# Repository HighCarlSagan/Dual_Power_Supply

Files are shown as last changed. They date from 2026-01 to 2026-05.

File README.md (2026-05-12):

# Universal PSU — 4A Dual-Output Power Supply






A compact mains-input dual-output bench supply built around an isolated AC-DC brick and two integrated buck modules. Provides clean, regulated 5 V and 3.3 V rails for hobby electronics — bench bringup, MCU dev boards, sensors, LEDs, and small actuator loads.

<p align="center">
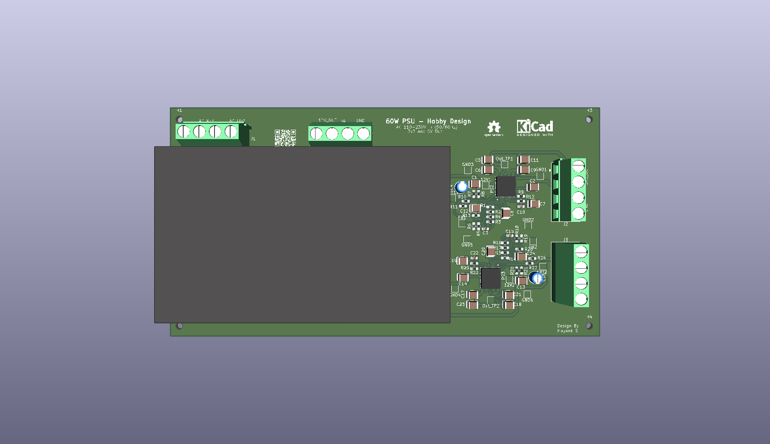
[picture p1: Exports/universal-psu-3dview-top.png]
PCB top render
  
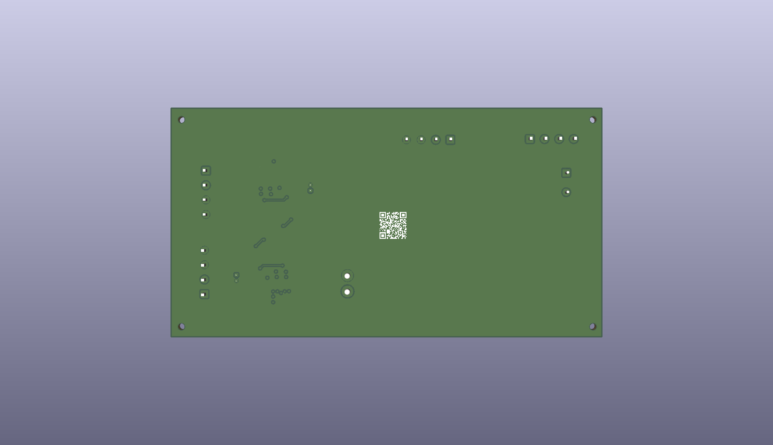
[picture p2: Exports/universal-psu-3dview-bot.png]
PCB bottom render
  
</p>

---

## Why I Built This

I wanted a single, always-on bench supply that I could leave plugged in and tap into for anything I'm prototyping: ESP32s, Pis, sensor breakouts, the Telegram-controlled lights board, whatever.

This was also a deliberate learning project on two fronts:

- **4-layer PCB layout for power applications** — getting the ground plane right, thermal management on the regulator footprints, and clean current return paths in a real-world design rather than a textbook example.
- **Mains-isolated module integration** — using a certified AC-DC brick lets me keep the dangerous side fully encapsulated while still building a useful, mains-powered project. A natural stepping stone before I take on a discrete flyback design later.

---

## Initial Requirements

These were the spec points I wrote down before any design work. The "Outcome" column shows what actually shipped.

| # | Requirement | Target | Outcome |
|---|---|---|---|
| 1 | Universal AC input | 110–230 V AC, 50/60 Hz | ✅ Met (IRM-60-15) |
| 2 | Output rail A | 5 V regulated | ✅ Met |
| 3 | Output rail B | 3.3 V regulated | ✅ Met |
| 4 | Continuous current per rail | 6 A | ⚠️ **4 A** — part ordered was TLVM14406 (4 A), not a 6 A variant. Sufficient for intended loads, scope kept. |
| 5 | Total power budget | ~60 W | ✅ Met (IRM-60-15 = 60 W headroom; DC-DC stage caps actual deliverable lower) |
| 6 | Form factor | Compact, no specific dimensions | ✅ 150 × 80 mm, 4-layer |
| 7 | Output protection (OCP, OVP) | TVS + fuse on outputs | ❌ **Missed in V1** — see [MkII Wishlist](#mkii-wishlist) |
| 8 | Status LEDs | Per-rail power-good indicators | ❌ **Missed in V1** — see [MkII Wishlist](#mkii-wishlist) |
| 9 | Reliability target | 3–4 years continuous service | TBD post-test |

---

## Specifications

| Parameter | Value |
|---|---|
| Input voltage | 110–230 V AC |
| Input frequency | 50 / 60 Hz |
| Intermediate rail | 15 V DC (internal only, see [Future Options](#future-options)) |
| Output 1 | 5 V @ 4 A |
| Output 2 | 3.3 V @ 4 A |
| Total output power | ~33 W deliverable from DC-DC stage<br>(60 W brick headroom) |
| PCB | 4-layer FR-4, 1.6 mm |
| Dimensions | 150 × 80 mm |
| Mounting | 4× M2 corner holes |
| Connectors | 4× 4-pin screw terminal blocks |

---

## Architecture

```
   AC Mains              Isolated brick           DC-DC stage              Outputs
  ┌─────────┐         ┌──────────────┐        ┌──────────────┐         ┌─────────┐
  │ 110-230 │────────▶│  IRM-60-15   │───15V─▶│ TLVM14406 #1 │────5V──▶│  J3     │
  │  V AC   │         │   60W AC-DC  │   │    └──────────────┘         └─────────┘
  └─────────┘         └──────────────┘   │    ┌──────────────┐         ┌─────────┐
                                         └───▶│ TLVM14406 #2 │────3.3V▶│  J4     │
                                              └──────────────┘         └─────────┘
```

The mains side is fully handled by the certified Mean Well IRM-60-15 brick. Everything on the PCB downstream is low-voltage DC, so the layout focused on thermal performance, ground-plane integrity, and switching-loop minimization rather than mains-side concerns.

---

## Key Components

| Reference | Part | Function |
|---|---|---|
| PS1 | Mean Well IRM-60-15 | 60 W universal-input AC-DC brick, 15 V output, fully isolated |
| PS2 | TI TLVM14406RCHR | Integrated 4 A SWIFT buck module, configured for 5 V |
| PS3 | TI TLVM14406RCHR | Integrated 4 A SWIFT buck module, configured for 3.3 V |
| J1–J4 | 4-pin screw terminals | Mains input, intermediate, and two output rails |

### Why the IRM-60 + TLVM14406 combo?

- **AC-DC brick over discrete flyback** — I wanted a reliable, working solution I could trust to leave running for years, without first having to learn off-line converter design, transformer winding, EMI compliance, and creepage/clearance. The IRM-60 is certified, isolated, and lets me focus the project on the DC-DC stage.
- **TLVM14406 over discrete switcher + inductor** — I'd worked with this family before. The integrated module collapses the inductor selection, compensation network design, and layout-critical switching loop into a known-good footprint. Fast path to a board that works.

---

## Connector Pinout

All four screw terminals share the same convention:

| Pin | Function |
|---|---|
| 1 | Power (V+) |
| 2 | Power (V+) |
| 3 | GND |
| 4 | GND |

Doubling power and ground pins lets each rail handle its rated current without exceeding terminal current limits and gives a cleaner mechanical termination for thicker wires.

| Connector | Use |
|---|---|
| J1 | AC mains input (Live / Neutral / Earth — see silkscreen) |
| J2 | 15 V intermediate (test point only — not for external loads in V1) |
| J3 | 5 V output |
| J4 | 3.3 V output |

---

## Repository Structure

```
universal-psu/
├── Exports/
│   ├── Gerber/                       # Production gerbers + drill files
│   ├── Photos/                       # Real PCB photos (added after assembly)
│   │   └── Testing/                  # Bench test photos & scope captures
│   ├── schematic.pdf                 # Full schematic export
│   ├── universal-psu-3dview-top.png  # PCB 3D render — top
│   ├── universal-psu-3dview-bot.png  # PCB 3D render — bottom
│   ├── universal-psu_bom.csv         # Bill of materials
│   ├── universal_psu_gerbers.zip     # Zipped gerbers for fab upload
│   └── universal-psu.net             # Netlist
├── Subsheets/
│   ├── DC_DC_Converter_5V.kicad_sch  # 5 V rail subsheet
│   └── DC_DC_Converter_3v3.kicad_sch # 3.3 V rail subsheet
├── libraries/                        # Custom KiCad symbols, footprints, 3D models
├── universal-psu.kicad_pro           # KiCad project
├── universal-psu.kicad_sch           # Top-level schematic
├── universal-psu.kicad_pcb           # PCB layout
├── LICENSE                           # CERN-OHL-P-2.0
└── README.md
```

---

## Bringup & Testing

> **Status:** PCBs back from fab, assembly in progress. Bringup test results will be posted in this section as they're collected.

### Planned bringup procedure

1. **Visual inspection** — solder bridges, especially around the AC-DC module and the screw terminal footprints
2. **Continuity check (power off)** — input-to-output isolation, no shorts on either rail
3. **Mains-up with no DC-side load** — verify 15 V intermediate rail comes up cleanly from the IRM-60 brick
4. **DC-DC bringup, no load** — verify 5 V and 3.3 V come up to spec (sanity-check the feedback divider math against measurement; resistor values to be verified during this step)
5. **Light load test** — 100 mA per rail, check ripple on a scope
6. **Stepped load test** — 0.5 A → 1 A → 2 A → 3 A → 4 A per rail, log:
   - DC output voltage (line/load regulation)
   - Output ripple (peak-to-peak)
   - Brick case temperature
   - TLVM14406 case temperature (thermal cam)
   - Input current draw (for a rough efficiency number)
7. **Thermal soak** — full load on both rails for 1 hour, log temperatures every 5 minutes

### Test results

*To be added in `Exports/Photos/Testing/` — scope captures, thermal images, and a bench-test summary table.*

| Test | Target | Measured | Notes |
|---|---|---|---|
| 5 V rail accuracy | 4.95 – 5.05 V | _TBD_ | |
| 3.3 V rail accuracy | 3.25 – 3.35 V | _TBD_ | |
| 5 V ripple @ 4 A | < 50 mV pp | _TBD_ | |
| 3.3 V ripple @ 4 A | < 50 mV pp | _TBD_ | |
| Brick temp @ full load | < 70 °C case | _TBD_ | |
| TLVM14406 temp @ 4 A | < 85 °C case | _TBD_ | |
| Line regulation | < 1 % | _TBD_ | |
| Load regulation | < 2 % | _TBD_ | |

---

## When To Use This Board

**Good fit:**
- Powering MCU dev boards (ESP32, RP2040, STM32 Nucleo, Pi Pico)
- Sensor breakouts, LCD modules, small displays
- LED strips and controllers (within 4 A budget)
- General benchtop hobby work where 5 V and 3.3 V are needed simultaneously

**Not a good fit:**
- Motor drives or anything inductive that kicks back significantly (no protection on V1)
- Audio circuits (no LC post-filtering for low-noise applications)
- Safety-critical or always-on industrial use (fuses and TVS missing on V1)
- Loads above 4 A continuous per rail

---

## Future Options

- **Expose 15 V intermediate as a third output** — already present internally, just needs a connector and trace fanned out. Useful for op-amp circuits, fan drives, or any project that wants a higher rail.
- **Output protection** — eFuse or polyfuse + TVS on each output rail.
- **Per-rail status LEDs** — power-good indicators tied to the TLVM14406 PG output.
- **3D-printed enclosure** — open-frame is fine for the bench, but a printed case would make this safer to leave plugged in long-term.

---

## MkII Wishlist

Honest list of what V1 missed that V2 should fix:

1. **Output protection** — no TVS, no fuses, no eFuses. A short on either output goes directly to the buck module's internal protection only.
2. **Status LEDs** — no visible indication that either rail is alive.
3. **Mounting hole placement** — corner holes are too close to the board edge, making the board awkward to mount in any standard enclosure. V2 should use rounded corners and proper standoff offsets.
4. **Silkscreen labeling** — connector pin functions need clearer markings on the board face.
5. **15 V tap connector** — needs a header.

---

## Manufacturing

Boards fabricated as standard 4-layer FR-4. Gerbers in `Exports/Gerber/` are compatible with JLCPCB, PCBWay, OSHPark, and similar fab houses.

**Fab specs used:**
- 4-layer, 1.6 mm FR-4
- 1 oz copper outer + inner
- ENIG surface finish recommended for finer pitch parts
- Default solder mask, white silkscreen

---

## Safety

> ⚠️ **DANGER — MAINS VOLTAGE**
>
> This board operates at 110–230 V AC. The mains-side energy can be lethal.
>
> The mains side is encapsulated inside the certified IRM-60-15 brick — no exposed mains-voltage traces exist on the PCB itself once the brick is mounted. However, the screw terminal carrying mains input (J1) and the brick's own input pins are exposed and must be enclosed before powering up.
>
> - Never operate without proper insulation around J1 and the brick's input side
> - Do not bypass or modify the AC-DC brick
> - Use a current-limited isolation transformer for first power-on if you have one available
> - Comply with local electrical codes
> - Not for medical, life-support, or safety-critical use
>
> **The author assumes no liability for injury, death, or property damage.**

---

## License

This project is licensed under the **CERN Open Hardware Licence Version 2 — Permissive (CERN-OHL-P-2.0)**.

You are free to:
- Use, modify, and distribute the design — commercially or non-commercially
- Create derivative works under any license you choose
- Use without sharing modifications back upstream

You must:
- Retain the original license notice and attribution

See [LICENSE](LICENSE) for the full text.

---

## Used By

This board powers the following projects in my portfolio:
- [PC_and_Light_Controller](https://github.com/HighCarlSagan/PC_and_Light_Controller) — Telegram-controlled UPS button + LED switching

---

## Author

**Mayank S (HighCarlSagan)** — [GitHub @HighCarlSagan](https://github.com/HighCarlSagan) · [highcarlsagan.dev](https://highcarlsagan.dev)

Designed: December 2025 · Boards back: April 2026 · Bringup: in progress

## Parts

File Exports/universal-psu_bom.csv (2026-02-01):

Reference | Qty | Value | DNP | Exclude from BOM | Exclude from Board | Footprint | Datasheet | MANUFACTURER | Manufacturer Part Number | Price | Vendor | Vendor Link | Description | Vendor Part Number
12V1,12V2 | 2 | 12V |  |  |  | TestPoint:TestPoint_Pad_2.0x2.0mm |  |  |  |  |  |  | test point
C1,C2,C13,C14 | 4 | 10u_50V_1210 |  |  |  | Capacitor_SMD:C_1210_3225Metric | https://www.yageogroup.com/content/datasheet/asset/file/KEM_C1002_X7R_SMD | KEMET | C1210C106M3RACTU | 28.2 |  | https://www.digikey.in/en/products/detail/kemet/C1210C106M3RACTU/2216507 | 10 µF ±20% 25V Ceramic Capacitor X7R 1210 (3225 Metric) | 399-C1210C106M3RACTUCT-ND
C3,C10,C15,C22 | 4 | 47n_16V_0603 |  |  |  | Capacitor_SMD:C_0603_1608Metric | https://mm.digikey.com/Volume0/opasdata/d220001/medias/docus/658/CL10B473KO8NNNC_Spec.pdf | KEMET | CL10B473KO8NNNC | 4.78 |  | https://www.digikey.in/en/products/detail/kemet/C0603C473K3RACTU/2200866 | 0.047 µF ±10% 16V Ceramic Capacitor X7R 0603 (1608 Metric) | 1276-2079-1-ND
C4,C16 | 2 | 100u_50V_1210 |  |  |  | Capacitor_THT:CP_Radial_D4.0mm_P2.00mm | https://www.yageogroup.com/content/datasheet/asset/file/KEM_A4002_EEV | KEMET | EEV107M050S9MAA | 41.6 |  | https://www.digikey.in/en/products/detail/kemet/EEV107M050S9MAA/6597872 | 100 µF 50 V Aluminum Electrolytic Capacitors Radial, Can - SMD 2000 Hrs @ 105°C | 399-EEV107M050S9MAACT-ND
C5,C6,C9,C11,C17,C18,C21,C23 | 8 | 22u_25V_1210 |  |  |  | Capacitor_SMD:C_1210_3225Metric | https://search.murata.co.jp/Ceramy/image/img/A01X/G101/ENG/GRM32ER71E226ME15-01.pdf | KEMET | GRM32ER71E226ME15L | 42.04 |  | https://www.digikey.in/en/products/detail/murata-electronics/GRM32ER71E226ME15L/4905640 | 22 µF ±20% 25V Ceramic Capacitor X7R 1210 (3225 Metric) | 490-10758-1-ND
C7,C19 | 2 | 2.2n_25V_1210 |  |  |  | Capacitor_SMD:C_1210_3225Metric | https://search.murata.co.jp/Ceramy/image/img/A01X/G101/ENG/GRM033R71E222KA12-01.pdf | KEMET | C0603C473K3RACTU | 4.78 |  | https://www.digikey.in/en/products/detail/kemet/C0603C473K3RACTU/2200866 | 0.047 µF ±10% 25V Ceramic Capacitor X7R 0603 (1608 Metric) | 399-C0603C473K3RACTUCT-ND
C8,C12,C20,C24 | 4 | 1u_25V_1210 |  |  |  | Capacitor_SMD:C_1210_3225Metric | https://www.yageogroup.com/content/datasheet/asset/file/KEM_C1002_X7R_SMD | KEMET | C1210C105K3RACTU | 100 |  | https://www.digikey.in/en/products/detail/kemet/C1210C105K3RACTU/2216479 | 1 µF ±10% 25V Ceramic Capacitor X7R 1210 (3225 Metric) | 399-C1210C105K3RACTUCT-ND
FB1,FB2 | 2 | FB |  |  |  | TestPoint:TestPoint_Pad_2.0x2.0mm |  |  |  |  |  |  | test point
GND1,GND2,GND3,GND4,GND5,GND6 | 6 | GND |  |  |  | TestPoint:TestPoint_Pad_2.0x2.0mm |  |  |  |  |  |  | test point
J1,J2,J3,J4 | 4 | Screw_Terminal_01x04 |  |  |  | TerminalBlock_Phoenix:TerminalBlock_Phoenix_MKDS-1,5-4-5.08_1x04_P5.08mm_Horizontal | https://www.phoenixcontact.com/us/products/1715048/pdfhttps://www.phoenixcontact.com/us/products/1715048/pdf | Phoenix Contact | 1715048 | 257 |  | https://www.digikey.in/en/products/detail/phoenix-contact/1715048/260628https://www.digikey.in/en/products/detail/phoenix-contact/1715048/260628 | 4 Position Wire to Board Terminal Block Horizontal with Board 0.197" (5.00mm) Through Hole | 277-1260-ND
Out_TP1,Out_TP2 | 2 | 5V |  |  |  | TestPoint:TestPoint_Pad_2.0x2.0mm |  |  |  |  |  |  | test point
PS1 | 1 | IRM-60-15 |  |  |  | Converter_ACDC:Converter_ACDC_MeanWell_IRM-60-xx_THT | http://www.meanwellusa.com/productPdf.aspx?i=687 | MEAN WELL USA Inc. | IRM-60-12 | 1327 |  | https://www.digikey.in/en/products/detail/mean-well-usa-inc/IRM-60-12/7704688 | 15V, 4A, 60W, Isolated, AC-DC, IRM60 | 1866-3063-ND
PS2,PS3 | 2 | TLVM14406RCHR |  |  |  | footprints:CONV_TLVM14406RCHR | https://www.ti.com/lit/ds/symlink/tlvm14404.pdf?ts=1731607059072 | Texas Instruments | TLVM14406RCHR | 742 |  | https://www.digikey.in/en/products/detail/texas-instruments/TLVM14406RCHR/25318374 | Non-Isolated PoL Module DC DC Converter 2 Output 0.8 ~ 9V 3A, 3A 3V - 36V Input | 296-TLVM14406RCHRCT-ND
R1,R5,R10,R11,R14,R18,R23,R24 | 8 | 10k_0.21W_0603 | DNP |  |  | Resistor_SMD:R_0603_1608Metric_Pad0.98x0.95mm_HandSolder | https://www.vishay.com/docs/20043/crcwhpe3.pdf | Vishay Dale | CRCW060310K0FKEAHP | 6.01 |  | https://www.digikey.in/en/products/detail/vishay-dale/CRCW060310K0FKEAHP/2222263 | 10 kOhms ±1% 0.333W, 1/3W Chip Resistor 0603 (1608 Metric) Automotive AEC-Q200, Pulse Withstanding Thick Film | 541-10.0KSCT-ND
R2,R7,R15,R20 | 4 | 31.6k_0.21W_0603 |  |  |  | Resistor_SMD:R_0603_1608Metric_Pad0.98x0.95mm_HandSolder | https://www.vishay.com/docs/28773/crcwce3.pdf | Vishay Dale | CRCW060331K6FKEAC | 2.56 |  | https://www.digikey.in/en/products/detail/vishay-dale/CRCW060331K6FKEAC/7924046 | 31.6 kOhms ±1% 0.1W, 1/10W Chip Resistor 0603 (1608 Metric) Thick Film | 541-5351-1-ND
R3,R16 | 2 | 100_0.21W_0603 |  |  |  | Resistor_SMD:R_0603_1608Metric_Pad0.98x0.95mm_HandSolder | https://www.vishay.com/docs/20043/crcwhpe3.pdf | Vishay Dale | CRCW0603100RFKEAHP | 6.01 |  | https://www.digikey.in/en/products/detail/vishay-dale/CRCW0603100RFKEAHP/2222245 | 100 Ohms ±1% 0.333W, 1/3W Chip Resistor 0603 (1608 Metric) Automotive AEC-Q200, Pulse Withstanding Thick Film | 541-100SCT-ND
R4,R17 | 2 | 52.3k_0.21W_0603 |  |  |  | Resistor_SMD:R_0603_1608Metric_Pad0.98x0.95mm_HandSolder | https://www.vishay.com/docs/28773/crcwce3.pdf | Vishay Dale | CRCW060352K3FKEAC | 2.56 |  | https://www.digikey.in/en/products/detail/vishay-dale/CRCW060352K3FKEAC/7924235 | 52.3 kOhms ±1% 0.1W, 1/10W Chip Resistor 0603 (1608 Metric) Thick Film | 541-5470-1-ND
R6,R13,R19,R26 | 4 | 0_0.21W_0603 | DNP |  |  | Resistor_SMD:R_0603_1608Metric_Pad0.98x0.95mm_HandSolder | https://www.vishay.com/docs/20043/crcwhpe3.pdf | Vishay Dale | CRCW06030000Z0EAHP | 4.86 |  | https://www.digikey.in/en/products/detail/vishay-dale/CRCW06030000Z0EAHP/2222231,https://www.digikey.in/en/products/detail/vishay-dale/CRCW06030000Z0EAHP/2222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 | 0 Ohms Jumper Chip Resistor 0603 (1608 Metric) Automotive AEC-Q200, Pulse Withstanding Thick Film | 541-0.0SBCT-ND
R8,R21 | 2 | 7.15k_0.21W_0603 |  |  |  | Resistor_SMD:R_0603_1608Metric_Pad0.98x0.95mm_HandSolder | https://www.vishay.com/docs/20043/crcwhpe3.pdf | Vishay Dale | CRCW06037K15FKEAHP | 6.9 |  | https://www.digikey.in/en/products/detail/vishay-dale/CRCW06037K15FKEAHP/2226271 | Resistor | 541-CRCW06037K15FKEAHPCT-ND
R9,R22 | 2 | 9.53k_0.21W_0603 |  |  |  | Resistor_SMD:R_0603_1608Metric_Pad0.98x0.95mm_HandSolder | https://www.vishay.com/docs/28773/crcwce3.pdf | Vishay Dale | CRCW06039K53FKEAC | 2.56 |  | https://www.digikey.in/en/products/detail/vishay-dale/CRCW06039K53FKEAC/7924391 | 9.53 kOhms ±1% 0.1W, 1/10W Chip Resistor 0603 (1608 Metric) Thick Film | 541-5606-1-ND
R12,R25 | 2 | 11k_0.21W_0603 |  |  |  | Resistor_SMD:R_0603_1608Metric_Pad0.98x0.95mm_HandSolder | https://www.vishay.com/docs/28773/crcwce3.pdf | Vishay Dale | CRCW060311K0FKEAC | 2.56 |  | https://www.digikey.in/en/products/detail/vishay-dale/CRCW060311K0FKEAC/7924120 | 11 kOhms ±1% 0.1W, 1/10W Chip Resistor 0603 (1608 Metric) Thick Film | 541-5146-1-ND
RT1,RT2 | 2 | RT |  |  |  | TestPoint:TestPoint_Pad_2.0x2.0mm |  |  |  |  |  |  | test point

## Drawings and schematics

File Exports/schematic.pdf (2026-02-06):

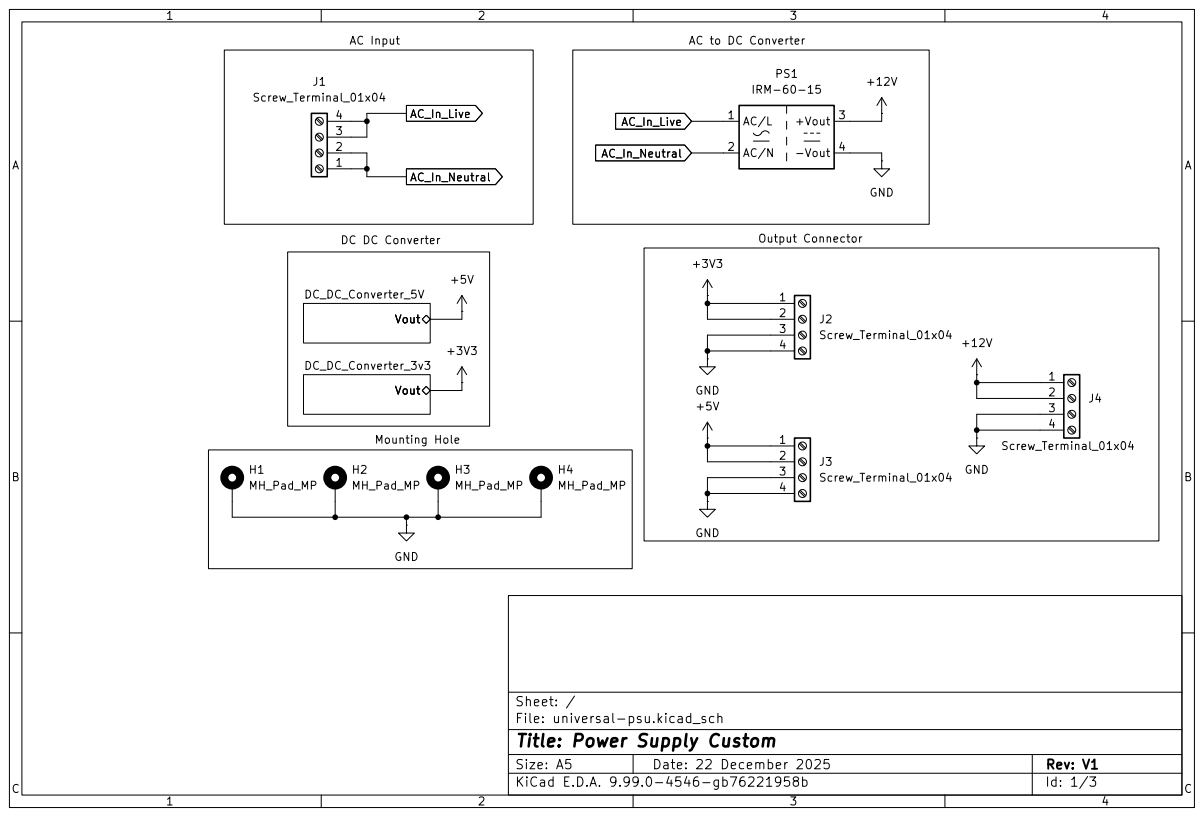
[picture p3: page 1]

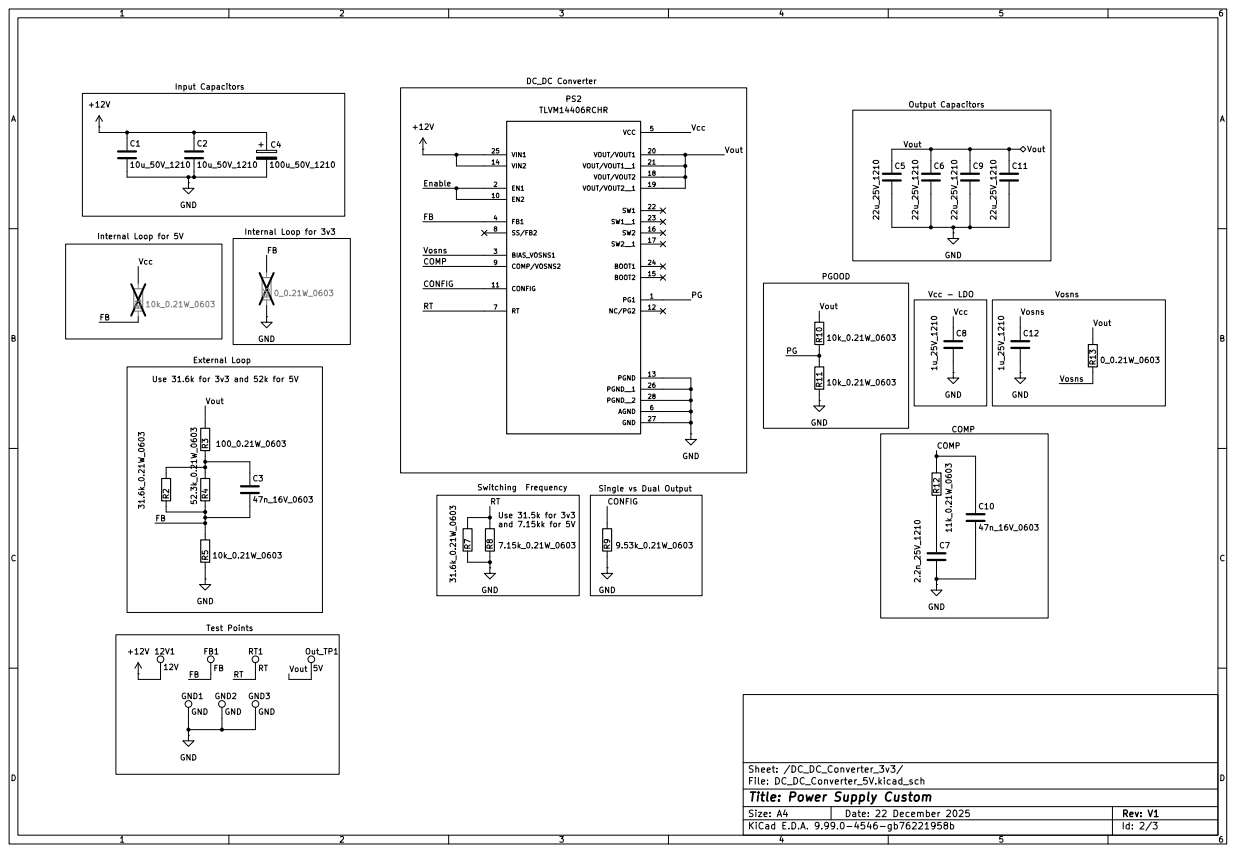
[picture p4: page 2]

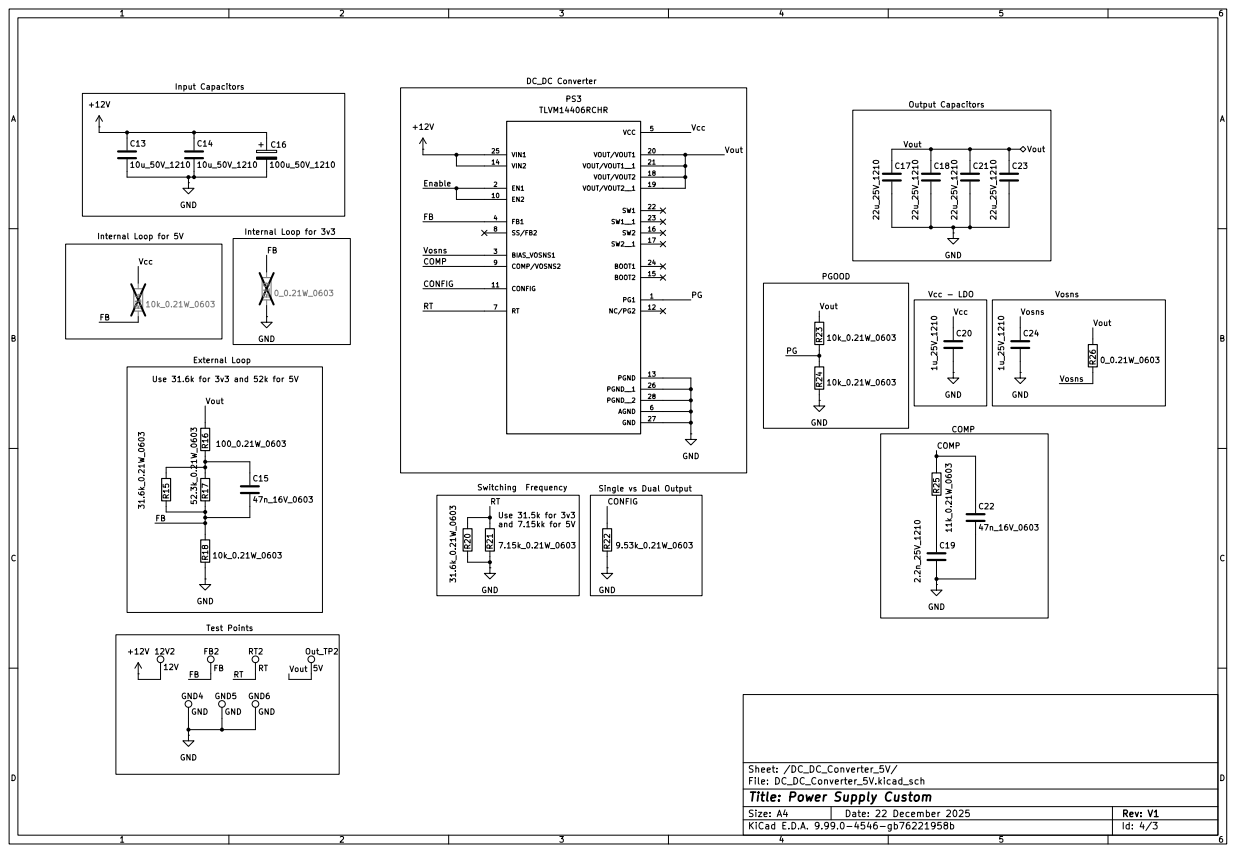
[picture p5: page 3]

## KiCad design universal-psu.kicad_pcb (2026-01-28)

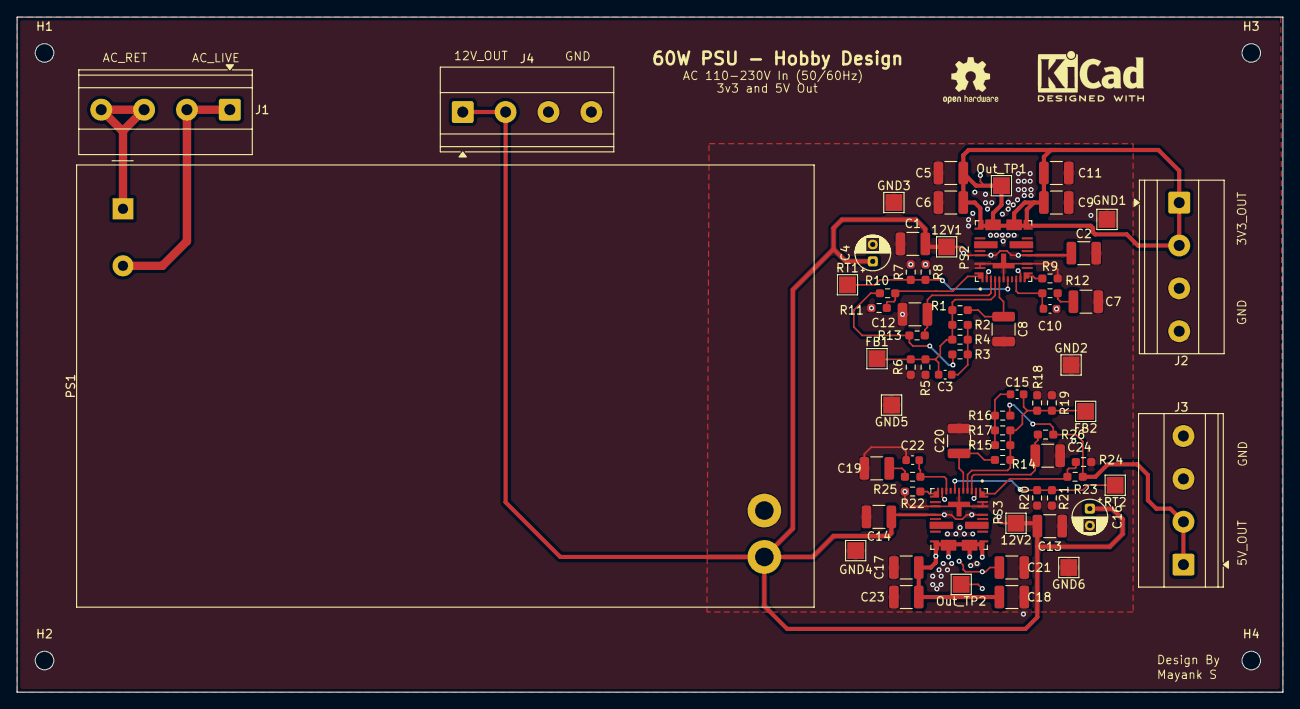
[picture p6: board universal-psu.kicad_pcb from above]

Board: 4 copper layers, 150.0 x 80.0 mm, 75 parts (0 on the bottom side), 26 nets.

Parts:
12V1, 12V2: 12V; TestPoint_Pad_2.0x2.0mm
C1, C2, C13, C14: 10u_50V_1210; C_1210_3225Metric
C3, C10, C15, C22: 47n_16V_0603; C_0603_1608Metric
C4, C16: 100u_50V_1210; CP_Radial_D4.0mm_P2.00mm
C5, C6, C9, C11, C17, C18, C21, C23: 22u_25V_1210; C_1210_3225Metric
C7, C19: 2.2n_25V_1210; C_1210_3225Metric
C8, C12, C20, C24: 1u_25V_1210; C_1210_3225Metric
FB1, FB2: FB; TestPoint_Pad_2.0x2.0mm
GND1, GND2, GND3, GND4, GND5, GND6: GND; TestPoint_Pad_2.0x2.0mm
H1, H2, H3, H4: MH_Pad_MP; MountingHole_2.2mm_M2
J1, J2, J3, J4: Screw_Terminal_01x04; TerminalBlock_Phoenix_MKDS-1,5-4-5.08_1x04_P5.08mm_Horizont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
Out_TP1, Out_TP2: 5V; TestPoint_Pad_2.0x2.0mm
PS1: IRM-60-15; Converter_ACDC_MeanWell_IRM-60-xx_THT
PS2, PS3: TLVM14406RCHR; CONV_TLVM14406RCHR
R1, R5, R10, R11, R14, R18, R23, R24: 10k_0.21W_0603; R_0603_1608Metric_Pad0.98x0.95mm_HandSolder
R2, R7, R15, R20: 31.6k_0.21W_0603; R_0603_1608Metric_Pad0.98x0.95mm_HandSolder
R3, R16: 100_0.21W_0603; R_0603_1608Metric_Pad0.98x0.95mm_HandSolder
R4, R17: 52.3k_0.21W_0603; R_0603_1608Metric_Pad0.98x0.95mm_HandSolder
R6, R13, R19, R26: 0_0.21W_0603; R_0603_1608Metric_Pad0.98x0.95mm_HandSolder
R8, R21: 7.15k_0.21W_0603; R_0603_1608Metric_Pad0.98x0.95mm_HandSolder
R9, R22: 9.53k_0.21W_0603; R_0603_1608Metric_Pad0.98x0.95mm_HandSolder
R12, R25: 11k_0.21W_0603; R_0603_1608Metric_Pad0.98x0.95mm_HandSolder
RT1, RT2: RT; TestPoint_Pad_2.0x2.0mm

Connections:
+3V3: C5.1, C6.1, C9.1, C11.1, J2.1, J2.2, Out_TP1.1 (1_1), PS2.18 (VOUT/VOUT2), PS2.19 (VOUT/VOUT2__1), PS2.20 (VOUT/VOUT1), PS2.21 (VOUT/VOUT1__1), R3.1, R10.1, R13.1
+5V: C17.1, C18.1, C21.1, C23.1, J3.1, J3.2, Out_TP2.1 (1_1), PS3.18 (VOUT/VOUT2), PS3.19 (VOUT/VOUT2__1), PS3.20 (VOUT/VOUT1), PS3.21 (VOUT/VOUT1__1), R16.1, R23.1, R26.1
+12V: 12V1.1 (1_1), 12V2.1 (1_1), C1.1, C2.1, C4.1, C13.1, C14.1, C16.1, J4.1, J4.2, PS1.3 (+Vout), PS2.14 (VIN2), PS2.25 (VIN1), PS3.14 (VIN2), PS3.25 (VIN1)
/DC_DC_Converter_3v3/COMP: C10.1, PS2.9 (COMP/VOSNS2), R12.1
/DC_DC_Converter_3v3/CONFIG: PS2.11 (CONFIG), R9.1
/DC_DC_Converter_3v3/Enable: PS2.2 (EN1), PS2.10 (EN2)
/DC_DC_Converter_3v3/FB: C3.2, FB1.1 (1_1), PS2.4 (FB1), R1.2, R2.2, R4.2, R5.1, R6.1
/DC_DC_Converter_3v3/PG: PS2.1 (PG1), R10.2, R11.1
/DC_DC_Converter_3v3/RT: PS2.7 (RT), R7.1, R8.1, RT1.1 (1_1)
/DC_DC_Converter_3v3/Vcc: C8.1, PS2.5 (VCC), R1.1
/DC_DC_Converter_3v3/Vosns: C12.1, PS2.3 (BIAS_VOSNS1), R13.2
/DC_DC_Converter_5V/COMP: C22.1, PS3.9 (COMP/VOSNS2), R25.1
/DC_DC_Converter_5V/CONFIG: PS3.11 (CONFIG), R22.1
/DC_DC_Converter_5V/Enable: PS3.2 (EN1), PS3.10 (EN2)
/DC_DC_Converter_5V/FB: C15.2, FB2.1 (1_1), PS3.4 (FB1), R14.2, R15.2, R17.2, R18.1, R19.1
/DC_DC_Converter_5V/PG: PS3.1 (PG1), R23.2, R24.1
/DC_DC_Converter_5V/RT: PS3.7 (RT), R20.1, R21.1, RT2.1 (1_1)
/DC_DC_Converter_5V/Vcc: C20.1, PS3.5 (VCC), R14.1
/DC_DC_Converter_5V/Vosns: C24.1, PS3.3 (BIAS_VOSNS1), R26.2
AC_In_Live: J1.3, J1.4, PS1.1 (AC/L)
AC_In_Neutral: J1.1, J1.2, PS1.2 (AC/N)
GND: C1.2, C2.2, C4.2, C5.2, C6.2, C7.2, C8.2, C9.2, C10.2, C11.2, C12.2, C13.2, C14.2, C16.2, C17.2, C18.2, C19.2, C20.2, C21.2, C22.2, C23.2, C24.2, GND1.1 (1_1), GND2.1 (1_1), GND3.1 (1_1), GND4.1 (1_1), GND5.1 (1_1), GND6.1 (1_1), J2.3, J2.4, J3.3, J3.4, J4.3, J4.4, PS1.4 (-Vout), PS2.6 (AGND), PS2.13 (PGND), PS2.26 (PGND__1), PS2.27 (GND), PS2.28 (PGND__2), PS3.6 (AGND), PS3.13 (PGND), PS3.26 (PGND__1), PS3.27 (GND), PS3.28 (PGND__2), R5.2, R6.2, R7.2, R8.2, R9.2, R11.2, R18.2, R19.2, R20.2, R21.2, R22.2, R24.2
unnamed: C3.1, R2.1, R3.2, R4.1
unnamed: C7.1, R12.2
unnamed: C15.1, R15.1, R16.2, R17.1
unnamed: C19.1, R25.2

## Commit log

2025-12-23 Initial commit: Universal PSU KiCad project
    [DC_DC_Converter_3v3.kicad_sch, DC_DC_Converter_5V.kicad_sch, universal-psu.kicad_pcb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]
2025-12-24 Layout import and schema fixes.
    [DC_DC_Converter_3v3.kicad_sch, DC_DC_Converter_5V.kicad_sch, universal-psu.kicad_pcb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]
2025-12-24 layout changes
    [DC_DC_Converter_3v3.kicad_sch, DC_DC_Converter_5V.kicad_sch, universal-psu.kicad_pcb]
2025-12-25 more layout
    [universal-psu.kicad_pcb]
2025-12-25 Layout closed, some DRC conflicts remain.
    [DC_DC_Converter_3v3.kicad_sch, DC_DC_Converter_5V.kicad_sch, universal-psu.kicad_pcb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]
2025-12-25 hopefully final design output, time for manufacturing
    [universal-psu-B_Cu.gbr, universal-psu-B_Mask.gbr, universal-psu-B_Paste.gbr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]
2025-12-25 docs: Add comprehensive README with specs, safety warnings, and project structure with license on the silkscreen cos why not
    [universal-psu.kicad_pcb]
2025-12-25 updated images
    [universal-psu.kicad_pcb]
2025-12-27 minor fixes
    [DC_DC_Converter_5V.kicad_sch, Digikey_BoM.xlsx, universal-psu.kicad_pcb]
2025-12-28 silkscreen and one part footprint and part number change for C3, C10, C15 and C22
    [DC_DC_Converter_5V.kicad_sch, Digikey_BoM.xlsx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]
2026-01-28 Connector change and silkscreen
    [DC_DC_Converter_5V.kicad_sch, universal-psu.kicad_pcb, universal-psu.kicad_sch]
2026-01-28 Gerbers and images updated
    [universal-psu-B_Cu.gbr, universal-psu-B_Mask.gbr, universal-psu-B_Paste.gbr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]
2026-02-01 Manufacturing Readiness
    [DC_DC_Converter_5V.kicad_sch, Universal_PSU.step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]
2026-02-06 final final manufacturing output
    [DC_DC_Converter_5V.kicad_sch, Universal_PSU.step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]
2026-05-10 docs: rewrite README with project structure, requirements table, and bringup plan; switch to CERN-OHL-P-2.0
